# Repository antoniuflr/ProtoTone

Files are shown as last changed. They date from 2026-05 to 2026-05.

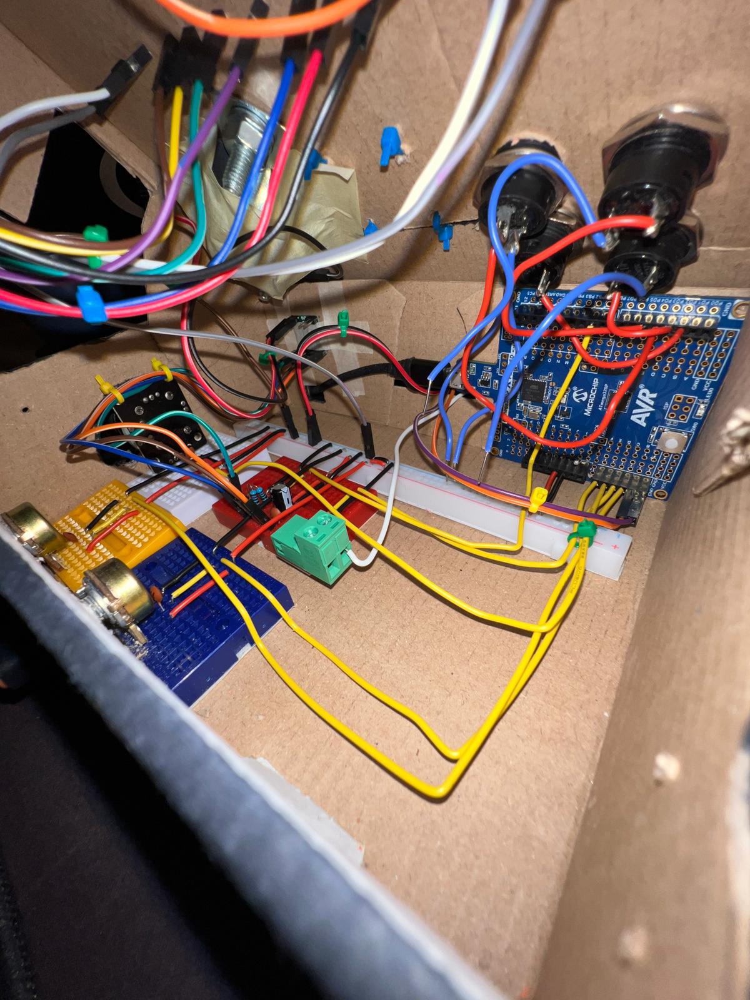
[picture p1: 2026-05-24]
Media/poza_hardware_2.jpeg

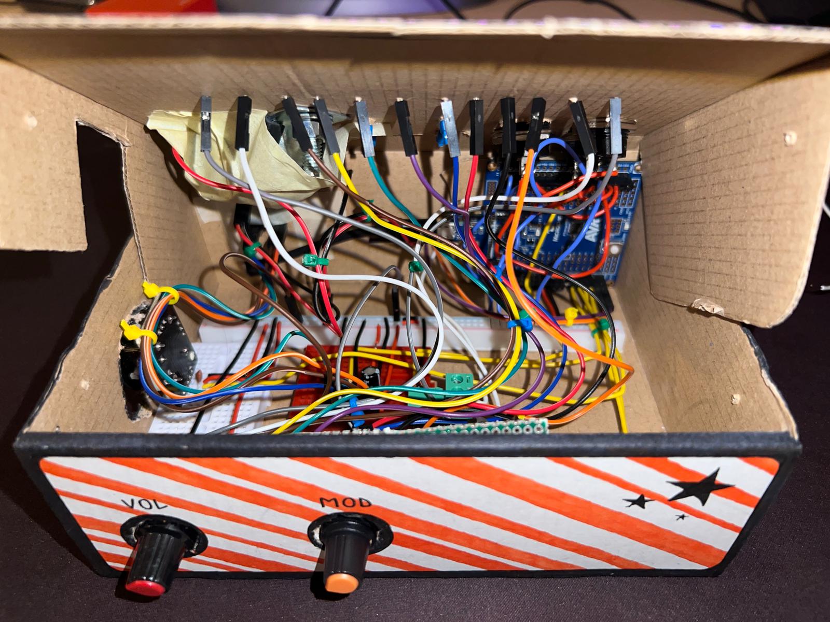
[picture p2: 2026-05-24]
Media/poza_hardware_1.jpeg

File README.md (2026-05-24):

# ProtoTone

ProtoTone is a small stylophone-style synthesizer built around the ATmega328P Xplained Mini. It uses a stylus and a resistor ladder to select notes, then generates audio with PWM and a small PAM8403 amplifier.

## Features

- 12-note chromatic keyboard using a resistor ladder
- Stylus-based note selection
- OLED status display over I2C
- PWM audio output on OC1A / PB1
- Square, saw and triangle waveforms
- Pitch bend using a joystick
- Vibrato control using a potentiometer
- Volume control using a potentiometer
- Hold mode
- Octave up/down buttons
- Status LED
- Serial debug output

## Hardware

Main components:

- ATmega328P Xplained Mini
- SSD1306 128x64 OLED display
- PAM8403 3W audio amplifier
- 4Ω / 3W speaker
- 10k potentiometers for volume and vibrato
- Analog joystick for pitch bend
- Resistor ladder keyboard
- Stylus contact
- Buttons for octave, waveform and hold

## Pin usage

| Function | ATmega328P / Arduino pin |
|---|---|
| Audio PWM | PB1 / D9 / OC1A |
| Notes ADC | PC0 / A0 |
| Pitch bend | PC1 / A1 |
| Vibrato | PC2 / A2 |
| Volume | PC3 / A3 |
| OLED SDA | PC4 / A4 / SDA |
| OLED SCL | PC5 / A5 / SCL |
| Octave down | D2 |
| Octave up | D3 |
| Waveform select | D4 |
| Hold | D5 |
| Status LED | D6 |

## How it works

The note keyboard is built as a resistor ladder. Each key produces a different voltage, read through `A0`. The software compares the ADC value with calibrated values and locks onto the closest stable note.

Once a note is detected, the code calculates its final frequency by applying octave shift, joystick pitch bend and vibrato. The frequency is converted into a phase increment and used by a phase accumulator to generate waveforms.

Timer1 runs Fast PWM on `OC1A` at 62.5 kHz. Timer2 runs an interrupt at 16 kHz and updates the PWM duty cycle with the next audio sample. The PWM output is filtered with an RC filter, then sent to the PAM8403 amplifier and speaker.

## Software notes

The code uses:

- `Adafruit_SSD1306` and `Adafruit_GFX` for the OLED
- `Wire` for I2C
- Timer1 for PWM audio output
- Timer2 Compare Match interrupt for audio sample generation
- ADC reads for note, pitch, vibrato and volume
- software debounce for buttons
- note hysteresis to avoid unstable note switching

## Build

The project is built with PlatformIO.

Required libraries:

```ini
lib_deps =
    adafruit/Adafruit SSD1306
    adafruit/Adafruit GFX Library

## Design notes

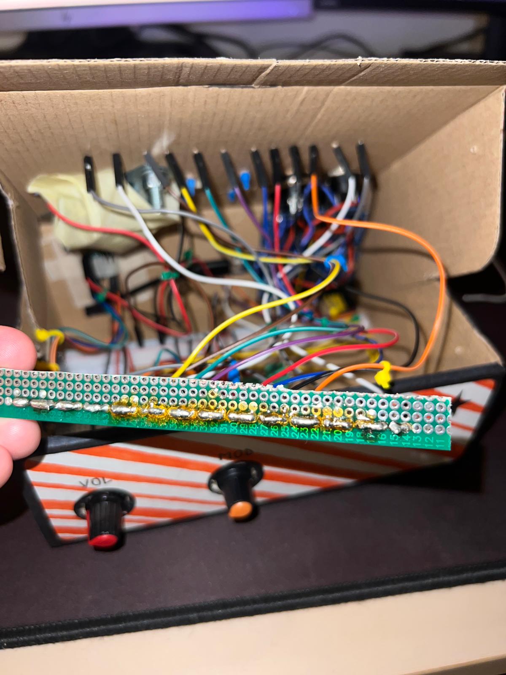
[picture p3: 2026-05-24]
Media/poza_hardware_4.jpeg

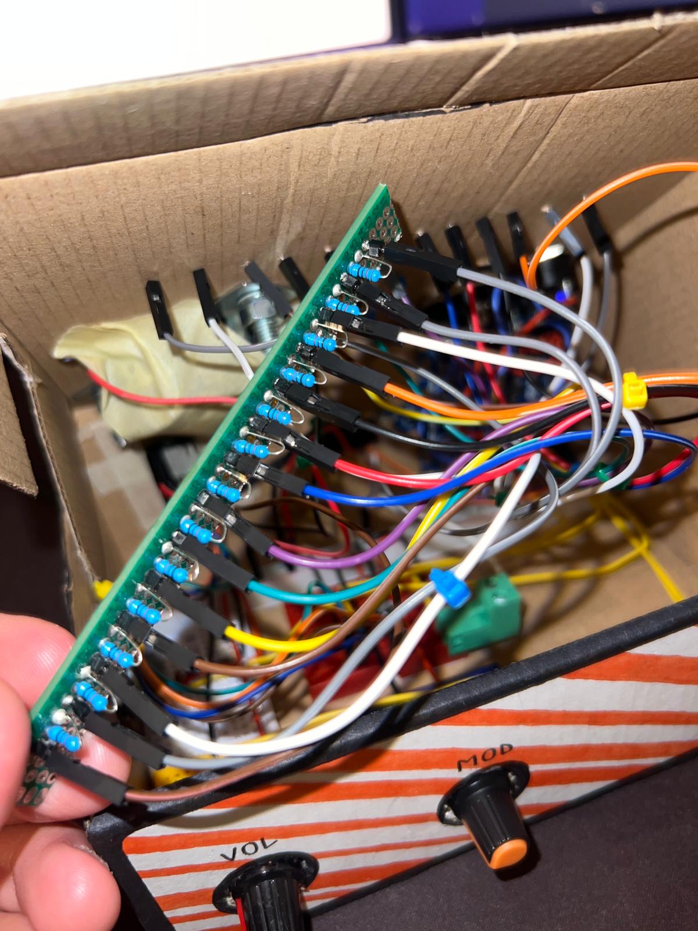
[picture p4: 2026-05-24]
Media/poza_hardware_3.jpeg

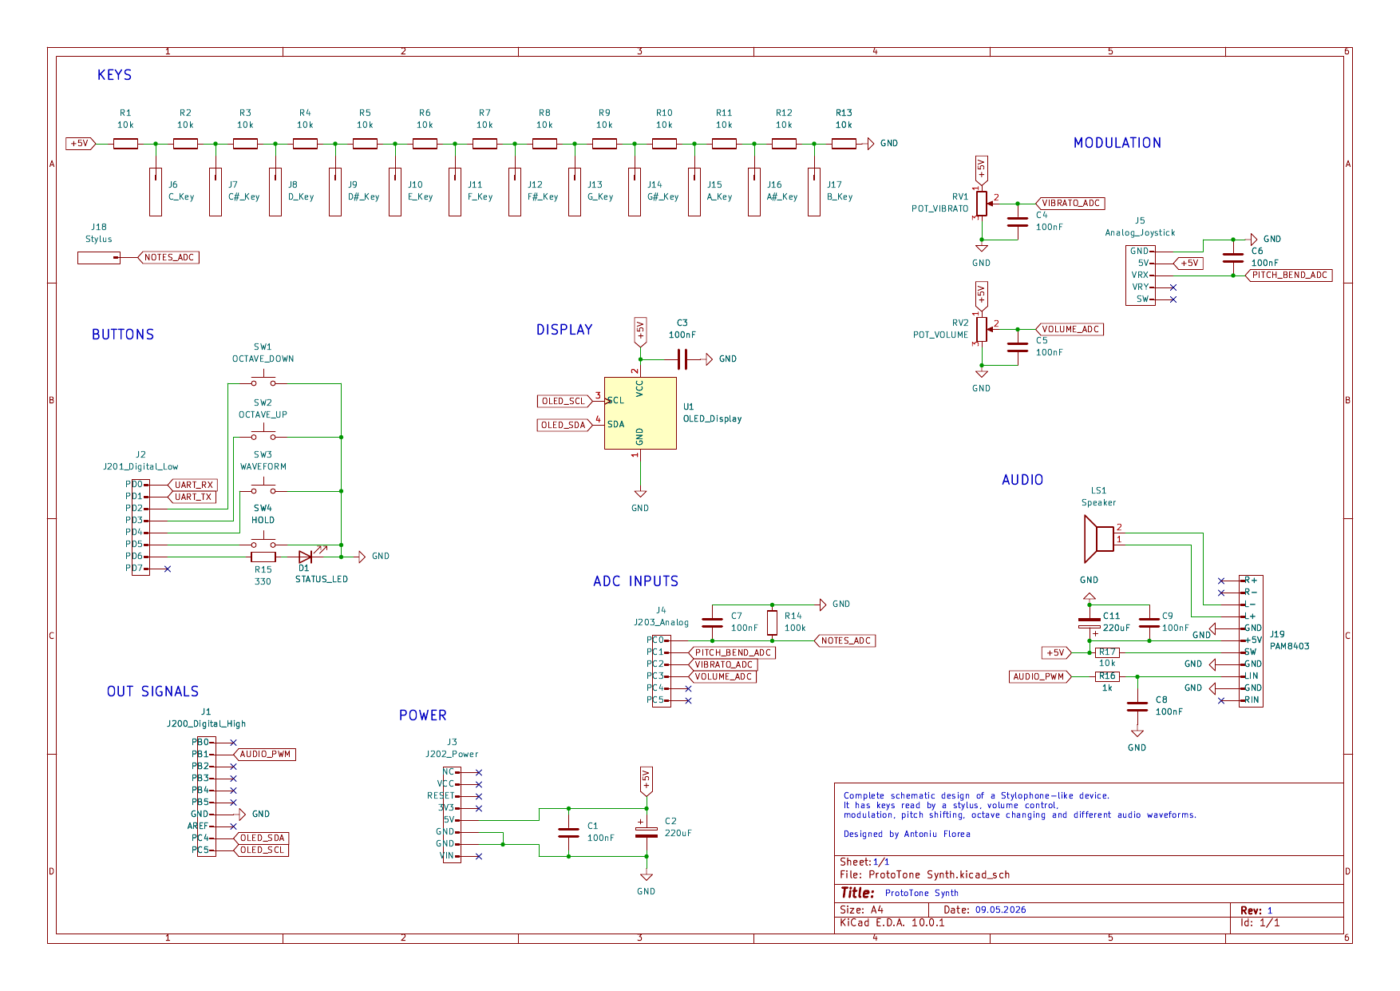
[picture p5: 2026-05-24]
Documents/schematic_florea_stefan_antoniu.png

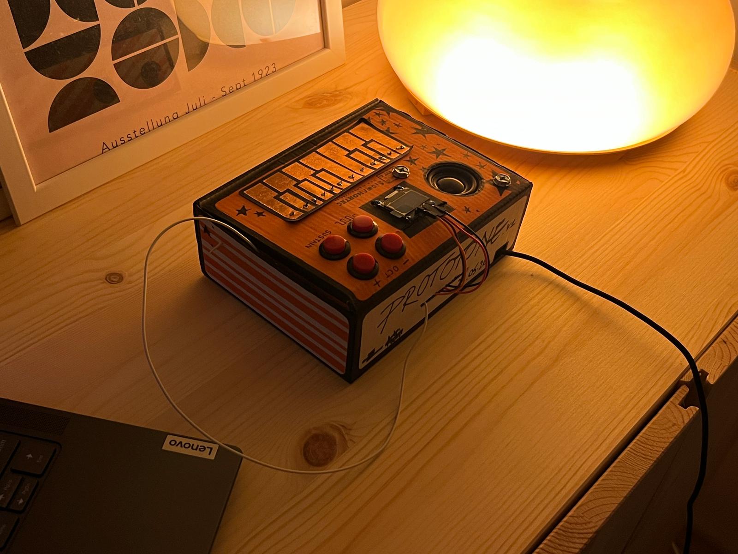
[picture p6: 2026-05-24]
Media/poza_spate.jpeg

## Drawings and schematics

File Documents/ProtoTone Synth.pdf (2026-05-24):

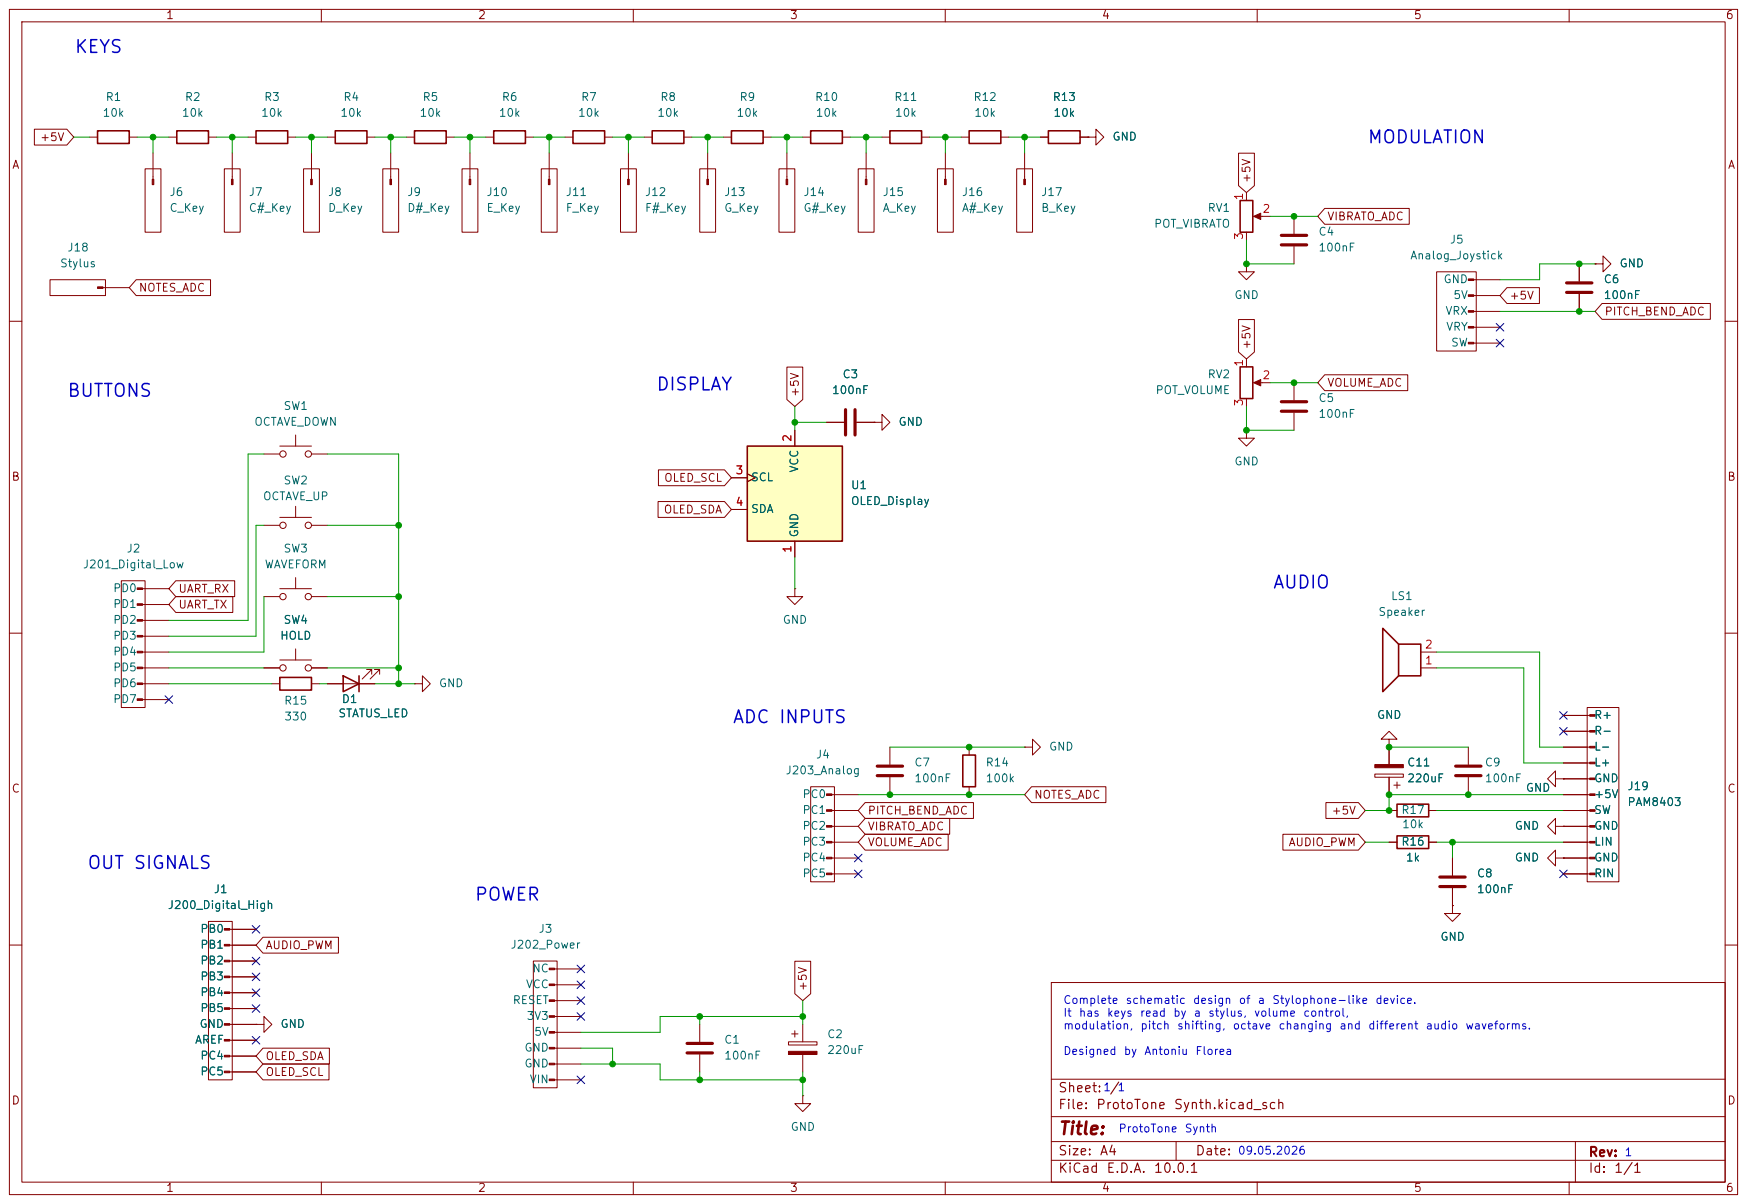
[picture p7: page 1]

Complete schematic design of a Stylophone-like device.
It has keys read by a stylus, volume control,

Size: A4 | Rev:
KiCad E.D.A. 10.0.1 | Id: 1/1

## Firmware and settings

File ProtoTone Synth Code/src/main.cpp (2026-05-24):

#include <Arduino.h>
#include <Wire.h>
#include <Adafruit_GFX.h>
#include <Adafruit_SSD1306.h>
#include <avr/interrupt.h>
#include <util/atomic.h>
#include <math.h>

// Screen constants
#define SCREEN_WIDTH 128
#define SCREEN_HEIGHT 64
#define OLED_RESET -1
#define OLED_ADDR 0x3C

// Arduino pin for audio
#define AUDIO_PIN 9

// Arduino pins for analog entries
#define NOTES_PIN A0
#define PITCH_PIN A1
#define VIBRATO_PIN A2
#define VOLUME_PIN A3

// Arduino pins for GPIO
#define BTN_OCT_DOWN 2
#define BTN_OCT_UP 3
#define BTN_WAVEFORM 4
#define BTN_HOLD 5
#define LED_STATUS 6

// Rate at which the code samples the audio
#define SAMPLE_RATE 16000.0f

// Safe thresholds for speaker
#define MIN_SAFE_FREQ 150.0f
#define MAX_SAFE_FREQ 2000.0f

// Safe space around the center of the joystick
#define PITCH_DEADZONE 25

// Display constructor
Adafruit_SSD1306 display(SCREEN_WIDTH, SCREEN_HEIGHT, &Wire, OLED_RESET);

// All the notes
const char* noteNames[12] = {
    "C", "C#", "D", "D#", "E", "F", "F#", "G", "G#", "A", "A#", "B"
};


// Notes frequencies
const float noteFreqs[12] = {
    261.63, 277.18, 293.66, 311.13,
    329.63, 349.23, 369.99, 392.00,
    415.30, 440.00, 466.16, 493.88
};

// Each note converted (measured on board)
const int noteAdcExpected[12] = {
    861, 737, 636, 553, 478, 413,
    354, 298, 244, 189, 133, 70
};


// Current position in waveform
volatile uint32_t phaseAcc = 0;

// Rate of navigation thorugh waveform
volatile uint32_t phaseInc = 0;

// Volume, scaling factor for waveform
volatile uint8_t audioVolume = 0;

// Waveform type
volatile uint8_t waveform = 0; // 0 square, 1 saw, 2 triangle

// Note active boolean
volatile bool noteActive = false;

// Current note
int currentNote = -1;

// Current frequency
float currentFreq = 0.0f;

// Current octave
int8_t octaveOffset = 0;

// Hold status boolean
bool holdEnabled = false;

// What note should be played while hold is enabled
int heldNote = -1;

// Values after conversion for notes, pitch, vibrato and volume
uint16_t notesAdc = 0;
uint16_t pitchAdc = 0;
uint16_t vibratoAdc = 0;
uint16_t volumeAdc = 0;

// Transform a frequency from Hz to a step in the waveform
uint32_t freqToPhaseInc(float freq) {
    // Clamps to not damage the speaker
    if (freq < MIN_SAFE_FREQ) freq = MIN_SAFE_FREQ;
    if (freq > MAX_SAFE_FREQ) freq = MAX_SAFE_FREQ;

    // phaseInc = frequency * 2^32 / sample_rate
    return (uint32_t)((freq * 4294967296.0f) / SAMPLE_RATE);
}

// Get median of reads
uint16_t smoothAnalogRead(uint8_t pin) {
    uint32_t sum = 0;

    // Add up 12 consecutive reads
    for (uint8_t i = 0; i < 12; i++) {
        sum += analogRead(pin);
        delayMicroseconds(120);
    }

    // Get median
    return sum / 12;
}

// Clamp read adc value to nearest note
int detectNearestNote(uint16_t adc) {
    int bestIndex = -1;

    // Maximum difference
    int bestDiff = 1024;

    for (int i = 0; i < 12; i++) {
        int diff = abs((int)adc - noteAdcExpected[i]);

        if (diff < bestDiff) {
            bestDiff = diff;
            bestIndex = i;
        }
    }

    if (bestDiff > 90) {
        return -1;
    }

    return bestIndex;
}

// Detect note with ADC unwanted fluctuation
int detectNoteStable(uint16_t adc) {
    // Static variables to stay the same during function calls
    // Current stabilized note
    static int lockedNote = -1;

    // How many consecutive reads are in the air
    static uint8_t airCounter = 0;

    // Potential new note
    static int candidateNote = -1;

    // How many times in a row we-ve seen the candidate
    static uint8_t candidateCounter = 0;

    // If ADC is below this value, we consider the stylus being in the air
    const int AIR_THRESHOLD = 35;

    // We change the note only if the new note is this close to other note
    const int SWITCH_MARGIN = 55;

    // How many consecutive air reads are necessary to stop the current nore
    const uint8_t AIR_RELEASE_COUNT = 4;

    // How many consecutive candidate reads to switch to it
    const uint8_t NOTE_CONFIRM_COUNT = 3;

    // ADC below threshold = air
    // If stylus doesn't make good contact for 1-2 reads the sound doesn't stop
    if (adc < AIR_THRESHOLD) {
        if (airCounter < AIR_RELEASE_COUNT) {
            airCounter++;
            return lockedNote;
        }

        // Reset
        lockedNote = -1;
        candidateNote = -1;
        candidateCounter = 0;
        return -1;
    }

    // No air
    airCounter = 0;

    // Get nearest note
    int nearestNote = detectNearestNote(adc);

    // If no note is found, return
    if (nearestNote < 0) {
        return lockedNote;
    }

    // If we don't have a locked note (no sound playing)
    if (lockedNote < 0) {
        // If we've seen this candidate we increment the counter
        if (nearestNote == candidateNote) {
            candidateCounter++;
        // If not, this is the candidate now
        } else {
            candidateNote = nearestNote;
            candidateCounter = 1;
        }

        // If we've seen the candidate enough times in a row, it becomes our locked note
        if (candidateCounter >= NOTE_CONFIRM_COUNT) {
            lockedNote = candidateNote;
            candidateNote = -1;
            candidateCounter = 0;
        }

        return lockedNote;
    }

    // If we already have a note and there is another
    // How close is adc value to the new note
    int nearestDiff = abs((int)adc - noteAdcExpected[nearestNote]);

    // How close is adc value to the current note 
    int currentDiff = abs((int)adc - noteAdcExpected[lockedNote]);

    // Hysteresis: we switch only if the new note is SWITCH_MARGIN closer to the adc value to prevent false switches
    if (nearestNote != lockedNote && nearestDiff + SWITCH_MARGIN < currentDiff) {
        if (nearestNote == candidateNote) {
            candidateCounter++;
        } else {
            candidateNote = nearestNote;
            candidateCounter = 1;
        }

        if (candidateCounter >= NOTE_CONFIRM_COUNT) {
            lockedNote = candidateNote;
            candidateNote = -1;
            candidateCounter = 0;
        }
    } else {
        // No clear switch, destroy candidate
        candidateNote = -1;
        candidateCounter = 0;
    }

    // Return satabilized note
    return lockedNote;
}

// Debounce button press
bool pressedOnce(uint8_t pin) {
    // Last time button was pressed
    static uint32_t lastTime[20] = {0};

    // Last state of pin
    static uint8_t lastState[20];

    // Initialize lastState
    static bool initialized[20] = {false};

    if (!initialized[pin]) {
        lastState[pin] = HIGH;
        initialized[pin] = true;
    }

    // Get current satate
    uint8_t state = digitalRead(pin);

    // If enough time has passed and the input changed from high to low we have a press
    if (lastState[pin] == HIGH && state == LOW && millis() - lastTime[pin] > 200) {
        lastTime[pin] = millis();
        lastState[pin] = state;
        return true;
    }

    // No change
    lastState[pin] = state;
    return false;
}

// Setup Timer1 to generate audio on AUDIO_PIN
void setupAudioPWM() {
    // Switch pin to output
    pinMode(AUDIO_PIN, OUTPUT);

    // Reset Timer1
    TCCR1A = 0;
    TCCR1B = 0;
    TCNT1 = 0;

    // Set Timer1 non-inverting PWM on OC1A
    TCCR1A |= (1 << COM1A1);
    
    // Set Fast PWM 8-bit
    TCCR1A |= (1 << WGM10);
    TCCR1B |= (1 << WGM12);

    // Select prescaler 1 => timer clock = cpu frequency = 16MHz
    TCCR1B |= (1 << CS10);

    // Set a default duty cycle
    OCR1A = 128;
}

// Set Timer2 to generate an interruption at 16kHz
void setupSampleTimer() {
    // Reset Timer2
    TCCR2A = 0;
    TCCR2B = 0;
    TCNT2 = 0;

    // Value at which we compare match
    OCR2A = 124;

    // Set timer to CTC
    TCCR2A |= (1 << WGM21);

    // Set prescaler at 8 so ISR runs at 16kHz
    TCCR2B |= (1 << CS21);

    // Activate interruption on compare match
    TIMSK2 |= (1 << OCIE2A);
}

// Interrupt routine that generates the sample
ISR(TIMER2_COMPA_vect) {
    // If no note is active or volume is 0 we set duty cycle to constant
    if (!noteActive || audioVolume == 0) {
        OCR1A = 128;
        return;
    }

    // Go further in waveform by phaseInc determined by current note
    phaseAcc += phaseInc;

    // phaseAcc is on 32 bits for accuracy, while our waveform is on 8, so we take the 8 most significant bits
    uint8_t p = phaseAcc >> 24;

    // Raw value of the wave
    uint8_t raw;

    switch (waveform) {
        // Square wave: first half is up, second is down
        case 0:
            raw = (p < 128) ? 255 : 0;
            break;

        // Saw wave: goes up linearly then jumps to 0
        case 1:
            raw = p;
            break;

        // Triangle wave: goes up linearly to max then descends linearly to 0
        case 2:
            raw = (p < 128) ? (p * 2) : (255 - ((p - 128) * 2));
            break;

        default:
            raw = 128;
            break;
    }

    // Transpose signal from 0:255 ro -128:127 for volume to scale the amplitude around the center, not to drag everything towards 0
    int16_t centered = (int16_t)raw - 128;
    int16_t scaled = (centered * audioVolume) / 255;

    // Set signal back to original interval
    OCR1A = (uint8_t)(scaled + 128);
}

// Display stuff
void updateDisplay() {
    static uint32_t lastDisplay = 0;

    // Update only after 150 ms
    if (millis() - lastDisplay < 150) {
        return;
    }

    lastDisplay = millis();

    display.clearDisplay();
    display.setCursor(0, 0);
    display.setTextSize(1);

    display.print("Note: ");
    if (currentNote >= 0) display.println(noteNames[currentNote]);
    else display.println("-");

    display.print("Freq: ");
    if (currentNote >= 0) {
        display.print((int)currentFreq);
        display.println(" Hz");
    } else {
        display.println("-");
    }

    display.print("Oct: ");
    display.println(octaveOffset);

    display.print("Wave: ");
    if (waveform == 0) display.println("Square");
    else if (waveform == 1) display.println("Saw");
    else display.println("Triangle");

    display.print("Hold: ");
    display.println(holdEnabled ? "ON" : "OFF");

    display.print("Vol: ");
    display.println(volumeAdc);

    display.print("Pitch: ");
    display.println(pitchAdc);

    display.print("Vib: ");
    display.println(vibratoAdc);

    display.print("ADC: ");
    display.println(notesAdc);

    display.display();
}

// Setup some stuff
void setup() {
    // Setup serial
  Serial.begin(9600);
  delay(200);

  Serial.println(F("ProtoTone booting..."));

  // Set pins
  pinMode(BTN_OCT_DOWN, INPUT_PULLUP);
  pinMode(BTN_OCT_UP, INPUT_PULLUP);
  pinMode(BTN_WAVEFORM, INPUT_PULLUP);
  pinMode(BTN_HOLD, INPUT_PULLUP);
  pinMode(LED_STATUS, OUTPUT);

  digitalWrite(LED_STATUS, LOW);
  Serial.println(F("Controls OK."));

  Wire.begin();

  // Setup display
  if (!display.begin(SSD1306_SWITCHCAPVCC, OLED_ADDR)) {
    Serial.println(F("OLED init failed."));
    while (1);
  }

  display.clearDisplay();
  display.setTextColor(SSD1306_WHITE);
  display.setTextSize(1);
  display.setCursor(0, 0);
  display.println(F("ProtoTone"));
  display.println(F("Init OK"));
  display.display();

  Serial.println(F("OLED OK."));

  // Setup timers
  setupAudioPWM();
  Serial.println(F("Audio PWM OK."));

  setupSampleTimer();
  Serial.println(F("Sample timer OK."));

  Serial.println(F("ADC OK."));
  Serial.println(F("Init complete."));

  delay(1000);
}

// Main loop
void loop() {
    // Get note from stylus
    notesAdc = smoothAnalogRead(NOTES_PIN);

    // get pitch from joystick
    pitchAdc = smoothAnalogRead(PITCH_PIN);

    // Get vibrato from potentiometer
    vibratoAdc = smoothAnalogRead(VIBRATO_PIN);

    // Get volume from potentiometer
    volumeAdc = smoothAnalogRead(VOLUME_PIN);

    // Get stabilized note
    int detectedNote = detectNoteStable(notesAdc);

    // If we got a stable note, set current note
    if (detectedNote >= 0) {
        currentNote = detectedNote;

        // Set held note if hold is enabled
        if (holdEnabled) {
            heldNote = detectedNote;
        }
    } else {
        // If no note is detected and hold is enabled and we have a held note set, set current note
        if (holdEnabled && heldNote >= 0) {
            currentNote = heldNote;
        } else {
            // No note :(
            currentNote = -1;
        }
    }

    // Go down an octave
    if (pressedOnce(BTN_OCT_DOWN)) {
        if (octaveOffset > -1) octaveOffset--;
    }

    // Go up an octave
    if (pressedOnce(BTN_OCT_UP)) {
        if (octaveOffset < 1) octaveOffset++;
    }

    // Cycle through waveforms
    if (pressedOnce(BTN_WAVEFORM)) {
        waveform = (waveform + 1) % 3;
    }

    // Toggle hold
    if (pressedOnce(BTN_HOLD)) {
        holdEnabled = !holdEnabled;

        if (!holdEnabled) {
            heldNote = -1;
        }
    }

    // Boolean for current note set
    bool active = currentNote >= 0;

    // Final augmented signal
    float finalFreq = 0.0f;

    // If there's a note set
    if (active) {
        // Get target frequency for the current note
        float baseFreq = noteFreqs[currentNote];

        // Double or half the frequency based on the octave offset (-1, 0 or 1)
        baseFreq *= powf(2.0f, octaveOffset);

        // Center pitch in 0
        int pitchCentered = (int)pitchAdc - 512;
        float bendSemitones = 0.0f;

        if (abs(pitchCentered) > PITCH_DEADZONE) {
            bendSemitones = (pitchCentered / 512.0f) * 12.0f;
        }

        // Aplitude of vibrato from potentiometer
        float vibratoDepth = (vibratoAdc / 1023.0f) * 0.5f;

        // Oscilates 5 times a second
        float vibratoRate = 5.0f;

        // Get seconds from starting
        float t = millis() / 1000.0f;

        // Final vibrato value based on sin oscilation
        float vibrato = sinf(2.0f * PI * vibratoRate * t) * vibratoDepth;

        // Apply everything
        finalFreq = baseFreq * powf(2.0f, (bendSemitones + vibrato) / 12.0f);

        // Clamp frequency
        if (finalFreq < MIN_SAFE_FREQ) finalFreq = MIN_SAFE_FREQ;
        if (finalFreq > MAX_SAFE_FREQ) finalFreq = MAX_SAFE_FREQ;
    }

    // Update frequency
    currentFreq = finalFreq;

    // Map volume potentiometer input to 0:170 to not overwhelm the speaker
    uint8_t vol = map(volumeAdc, 0, 1023, 0, 170);

    // Atomic operations on variables used by Timer2 ISR
    // This stops interruptions temporarily while we update critical variables to not read while they are written
    ATOMIC_BLOCK(ATOMIC_RESTORESTATE) {
        // Set if note is active
        noteActive = active;

        // Set increment in waveform
        phaseInc = active ? freqToPhaseInc(finalFreq) : 0;

        // Set volume
        audioVolume = active ? vol : 0;

        // If not active, set default
        if (!active) {
            OCR1A = 128;
        }
    }

    // Are we playing music or nah? Now visual
    digitalWrite(LED_STATUS, active ? HIGH : LOW);
    updateDisplay();

    // Delay to save on reads and writes
    // Audio is not affected due to it being generated in the Timer2 ISR
    delay(5);
}
